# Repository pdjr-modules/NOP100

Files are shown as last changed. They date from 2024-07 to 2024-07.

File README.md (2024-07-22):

# NOP100

The **NOP100** project implements an
[NMEA 2000](https://en.wikipedia.org/wiki/NMEA_2000)
interface module with twin
[MikroBUS](https://www.mikroe.com/mikrobus)
sockets which allow specialisation of function by the addition of
[Click](https://www.mikroe.com/click) expansion cards.

[**NOP100** hardware](./hardware/README.md)
is based on the Teensy 4.0 micro-controller supported by a CAN
transceiver, parasitic power supply and a user configuration
interface.

[**NOP100** firmware](./firmware/README.md)
manages NMEA 2000 connectivity, user interaction and module
configuration and is easily extended by the addition of firmware
dedicated to operation of the installed MikroBus cards and the
integration of their function with NMEA 2000.

## Project organisation

```
NOP100/
  + firmware/            # NOP100 firmware...
    + modules/           # Folders for module specialisations
      + NOP100-SIM/        # Specialisation defining an NMEA switch input module
        + defines.h
        + definitions.h
        + includes.h
        + loop.h
        + setup.h
      + another module specialisation/
      + .../
    + NOP100.cpp         # NOP100 main application 
    + README.md
    + defines.h          # Symbolic link to a module specialisation
    + definitions.h      #   "       "
    + includes.h         #   "       "
    + loop.h             #   "       "
    + setup.h            #   "       "
  + hardware/            # NOP100 hardware...
    + gerber/            # Gerber files for PCB fabrication
    + kicad/             # Kicad design for the NOP100 motherboard
    + README.md
```

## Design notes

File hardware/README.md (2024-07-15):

# NOP100 hardware

This project thread provides a circuit design and PCB layout for an
NMEA 2000 interface module which uses
[MikroBus](https://www.mikroe.com/mikrobus)
[Click](https://mikroe.com/click) cards as its real-world interfaces.

The module is based on the
[Teensy 4.0](https://www.pjrc.com/teensy_40)
micro-controller supported by an
[MCP2551](https://www.microchip.com/en-us/product/mcp2551)
CAN transceiver, and single or twin
[Murata](https://www.murata.com/en-eu/)
power supplies.

<table border="0">
<tr>
<td width="50%">

</td>
<td>
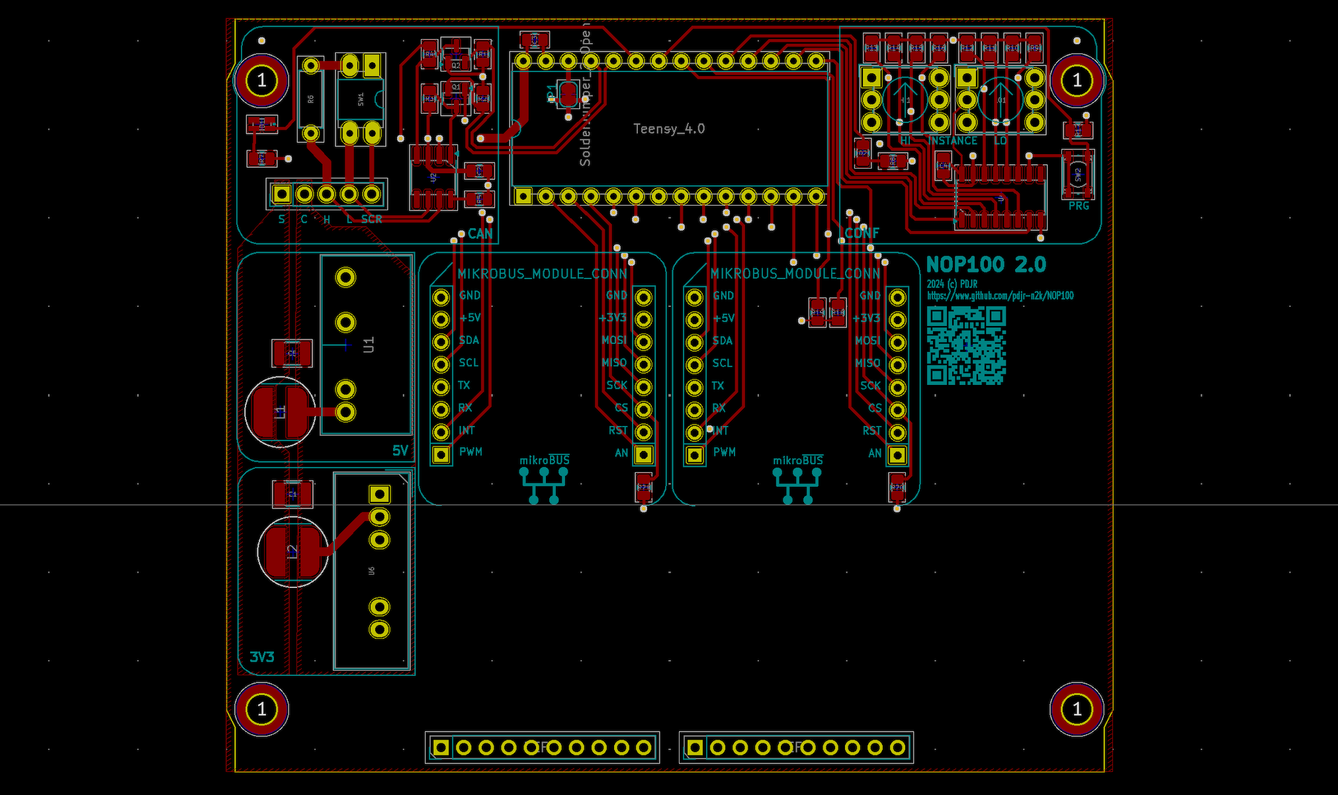
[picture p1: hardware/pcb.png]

</td>
</tr>
</table>

See [NOP100/firmware](../firmware/) for a C++ pattern and associated
libraries that can be used as a basis for implementing firmware which
exploits this hardware design.

## Design elements

### PCB and enclosure

The four-layer PCB is suitable for use in a
[Hammond 1591GSFLBK case](https://docs.rs-online.com/b790/A700000007521666.pdf)
and uses both surface-mount and through-hole components.

### Microcontroller

[Teensy 4.0](https://www.pjrc.com/store/teensy40.html).

### Power supplies

The module is a dual-voltage (5VDC/3.3VDC) design and is powered from
the host NMEA bus 12VDC supply.

A DC-DC converter outputs 5VDC 400mA to the microcontroller and CAN
transceiver.
In situations where the installed MikroBus modules have a current draw
of less that 250mA the Teensy's on-board 3.3VDC voltage regulator can
be used as the supply for all 3.3VDC consumers by making a solder
bridge connection at JP1.

If the Teensy's 250mA limit is insufficient for MikroBus consumers,
then a 3.3VDC 600mA DC-DC converter can be installed on the module PCB
(in which case the solder-bridge connection must not be made).

### CAN interface

An MCP-2551/IP CAN transceiver converts data on the NMEA bus
(CAN-H/CAN-L) to signals suitable for use by the microcontroller CAN
interface.
Input and output signals are level-shifted to 3.3VDC for compatability
with the Teensy 4.0.

A switch switch-selectable 120 Ohm bus termination resistor allows the
module to be used as either an NMEA drop or terminal node and a second
switch allows the NMEA bus shield to be connected to the module GND.

An activity indicator LED shows when the CAN interface is transmitting.

### Configuration interface

The configuration interface consists of two 4-bit rotary switches, a
momentary tactile switch and an LED.
The rotary switches are used to set the module's NMEA instance but can
also be used in concert with the tactile switch to save module
configuration parameters to EEPROM.

### MikroBus sockets

The **NOP100** hardware is specialised by inserting appropriate MikroBus
Click modules into the two MikroBus connector sockets.

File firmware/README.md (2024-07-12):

# NOP100/firmware

```NOP100.cpp``` implements a runnable, extensible, firmware for
[NOP100-based hardware](../hardware/README.md).

The files defines.h, definitions.h, includes.h, loop.h and setup.h
allow specialisation of NOP100 to a particular application by
extending and overriding some core functionality.

If the specialisation files are absent, the firmware creates an NMEA
2000 device with Class Code 10 (System Tools) and Function Code 130
(Diagnostic).
The created device is entirely passive.

Supplying functional content in the specialisation files allows the
construction of a useful NMEA 2000 application.
The recommended way of doing this is to create a folder under the
```modules/``` directory for a planned application and to populate this
with specialisation files that become the target of symbolic links in
the NOP100 folder.

By way of illustration, the ```modules/NOP100-SIM``` folders contains
code which specialises the NOP100 firmware so that it acts as an NMEA
2000 switch input module.
The extended firware supports one or two
[MikroE 5981]()
modules as the external switch input interface.

The modules/CLICK5981 folder, for example, 
Most useful applications will exploit interfaces implemented by
MikroBus modules which plug into the NOP100 motherboard and it is
[SIM108 - NMEA 2000 switch input module](https://www.github.com/preeve9534/SIM108/)
project is based on NOP100 and gives a working example of a real-world
application.

## Module configuration

NOP100 treats persistent configuration data as a simple byte array and
provides a user interface which allows the hardware DIL switch to be  
used sequentially to specify a storage address and the value to be
stored at that address.
This restricts the configuration data cache to a size of 256 bytes with
254 bytes available to the application.
The Teensy microcontroller has a about 1KB of EEPROM available and if
you want to access more than 256 bytes of this storage then you will
need to override NOP100's simple configuration model with a more
elaborate one of your own.
If you do this, make sure that your application configuration data
leaves address locations 0 and 1 for use by NOP100.

| Address | Saved value |
| ---:    | :---        |
| 0       | CAN source address. Not available for application use. |
| 1       | Module instance number. Not available for application use. |
| 2...    | Available for application use. |

Entry of configuration data into NOP100 requires a value to be set on
the PCB's DIL switch and then confirmed by press and release of the PRG
button.
A short press of PRG signifies the entry of a data value; a long press
of PRG signifies entry of an address and, in this latter case, the
expectation is that address entry will promptly be followed by the
entry of a data value which should be stored at the pre-set address.

If a value is entered without a preceeding address then the entered
value is stored at address 1 and will become the module's new instance
number.

Storage locations with an address greater than or equal to two are
intended for application configuration data and entry of this data
requires the entry of an address followed by entry of the value to be
stored at this address.

When an address is entered, the transmit LED will flash rapidly
indicating that the system is waiting for entry of a data value.
If a data value is not entered within one minute the data entry protocol
will self-cancel (the transmit LED will stop flashing).

In ```NOP100.cpp``` the configuration process is handled by the
```prgButtonHandler(bool _state_, int _value_)``` function which is
called each time the PRG button is operated.
*state* will be true if the PRG button has been released or false if
the PRG button has been pressed.
In either case, *value* will be set to the current value read from the
DIL switch.

You can override NOP100's built-in behaviour by overriding the button
handler in ```module-declarations.inc```.
For example, the following code disables configuration entirely:
```
#define PRG_BUTTON_HANDLER
void prgButtonHandler(bool state, int value) {
   return;
}
```

## HOW TO

1. Create parent folder for your new application.
   ```
   $> mkdir n2k-projects
   $> cd n2k-projects
   ```
2. Clone a copy of the Arduino firmware build project and this
   project into separate sub-folders.
   ```
   $> git clone https://github.com/preeve9534/firmware-factory
   $> git clone https://github.com/preeve9534/NOP100
   ```
3. Make a directory for your new project and populate it.
   ```
   $> mkdir myapp
   $> cd myapp
   $> cp ../NOP100/NOP100.cpp myapp.cpp
   $> cp ../NOP100/*.inc .
   $> cd ..
   ```
   You can now delete the NOP100 project.
   ```
   rm -rf NOP100
   ```
4. Set up the build environment so that it points to your new
   project.
   ```
   $> cd firmware-factory/sketch
   $> rm src
   $> ln -s ../../myapp src
   $> cd ../..
   ```
   At this juncture you should be able to open the firmware-factory 
   project in your preferred build environment (I use Code) and
   compile a firmware for your application which does nothing. Well,
   not very much.
5. Edit the ```.inc``` files downloaded at (3) to tailor and
   extend the module firmware to the requirements of your
   application.  DO NOT MODIFY myapp.cpp.

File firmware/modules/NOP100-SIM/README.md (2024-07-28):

# NOP100-SIM

This firmware extension for
[NOP100](https://www.github.com/pdjr-n2k/NOP100)
supports one or two
[MikroE-5981 Digi Isolator 2 Click]()
MikroBus expansion cards providing an NMEA interface to a maximum of
sixteen external switch input channels.

Switch input channels are consolidated into a single NMEA switch bank
whose status is reported by broadcast of a PGN 127501 Binary Switch
Status message once every two seconds or immediately when a state
change is detected on any input channel.

## Hardware requirement

* 1 x NOP100 motherboard;
* A maximum of two [MikroE-5981 Digi Isolator 2 Click]() expansion cards.

## Build

Building the firmware requires that both
[firmware-factory]()
and
[NOP100](https://www.github.com/pdjr-n2k/NOP100)
are installed locally in the locations pointed to by ```${FF}``` and
```${NOP100}```.

```
$> cd "${FF}/sketch"
$> ln -s "${NOP100}/firmware" src
$> pushd src ; ./link-module NOP100-SIM ; popd
$> pio run
```

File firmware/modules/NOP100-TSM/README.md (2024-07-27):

# NOP100-TSM

This sub-project provides a firmware extension for
[NOP100](https://www.github.com/pdjr-n2k/NOP100)
which implements an 8-channel NMEA 2000 temperature sensor module.

The module supports up to eight
[DS18B20](https://www.analog.com/media/en/technical-documentation/data-sheets/ds18b20.pdf)
digital thermometers.

A **NOP100-TSM** module broadcasts a
[PGN 130316 Temperature, Extended Range](https://www.nmea.org/Assets/nmea%202000%20pgn%20130316%20corrigenda%20nmd%20version%202.100%20feb%202015.pdf)
message once every five seconds.

## Hardware requirement

* 1 x NOP100 motherboard;
* 1 x [MikroE 1892 I2C 1-Wire Click](https://www.mikroe.com/i2c-1-wire-click) expansion card;
* Up to 8 x DS18B20 temperature sensors.

## Build

Building the firmware requires that both
[firmware-factory]()
and
[NOP100](https://www.github.com/pdjr-n2k/NOP100)
are installed locally in the locations pointed to by ```${FF}``` and
```${NOP100}```.

```
$> cd "${FF}/sketch"
$> ln -s "${NOP100}/firmware" src
$> pushd src ; ./link-module NOP100-TSM ; popd
$> pio run
```

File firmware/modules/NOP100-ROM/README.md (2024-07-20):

# NOP100-ROM - NMEA 2000 relay output module

NOP100-ROM is a 6-channel NMEA 2000 relay output module based on 
[NOP100](https://www.github.com/pdjr-n2k/NOP100)
hardware and firmware.

NOP100-ROM exploits the
[MikroE 5981 Relay 5 Click]()
module as its external switch interface.
One or two modules can be plugged into the NOP100's MikroBus sockets
giving a maximum of 6 output channels.

NOP100-ROM firmware can be linked into the NOP100 source code by
executing the following command in the ```NOP100/firmware``` folder.
```
$> ./link-module NOP100-ROM
```
Subsequently, compiling code in ```NOP100/firmware/src``` folder will
generate NOP100-ROM firmware.

## NMEA interface

**NOP100-ROM** broadcasts a PGN 127501 Binary Switch Status message
once every two seconds or immediately when a state change is detected
on a relay on any of the connected MikroE 5675 modules.

**NOP100-ROM** listens for PGN 127502 messages and updates relays on
connected MikroE 5675 modules to reflect the commanded states.

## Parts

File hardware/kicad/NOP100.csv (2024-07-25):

Source: | /Users/preeve/Documents/GitHub/NOP100/hardware/kicad/NOP100.kicad_sch
Date: | Thursday, July 25, 2024 at 04:07:12 PM
Tool: | Eeschema 7.0.11
Generator: | /Applications/KiCad/KiCad.app/Contents/SharedSupport/plugins/bom_csv_grouped_by_value.py
Component Count: | 45
Collated Components:
Item | Qty | Reference(s) | Value | LibPart | Footprint | Datasheet | DNP
1 | 1 | C1 | 330nF | Device:C_Small | Resistor_SMD:R_1210_3225Metric | ~
2 | 3 | C2, C3, C4 | 100nF | Device:C_Small | Resistor_SMD:R_0805_2012Metric | ~
3 | 1 | C5 | 22uF | Device:C_Small | Resistor_SMD:R_1210_3225Metric | ~
4 | 1 | CON1 | CLICK MODULE 0 | pdjr:MIKROBUS_MODULE_CONN | plop:MIKROBUS_HOST_CONN
5 | 1 | CON2 | CLICK MODULE 1 | pdjr:MIKROBUS_MODULE_CONN | plop:MIKROBUS_HOST_CONN
6 | 1 | D1 | LED | Device:LED | LED_SMD:LED_Kingbright_APHBM2012_2x1.25mm | ~
7 | 1 | D2 | LED | Device:LED | Resistor_SMD:R_0805_2012Metric | ~
8 | 2 | HI1, LO1 | SW_Coded | Switch:SW_Coded | pdjr:Nidec_Copal_SH-7010C | ~
9 | 1 | J1 | CAN | Connector:Screw_Terminal_01x05 | Connector_PinHeader_2.54mm:PinHeader_1x05_P2.54mm_Vertical | ~
10 | 1 | JP1 | SolderJumper_2_Open | Jumper:SolderJumper_2_Open | Jumper:SolderJumper-2_P1.3mm_Bridged_RoundedPad1.0x1.5mm | ~
11 | 1 | L1 | 15uH | Device:L_Small | Inductor_SMD:L_Bourns_SRN6045TA | ~
12 | 1 | L2 | 500uH | Device:L_Small | Inductor_SMD:L_Bourns_SRN6045TA | ~
13 | 2 | Q1, Q2 | BSS138 | Transistor_FET:BSS138 | Package_TO_SOT_SMD:SOT-23 | https://www.onsemi.com/pub/Collateral/BSS138-D.PDF
14 | 4 | R1, R2, R3, R4 | 10K 0.125W | Device:R | Resistor_SMD:R_0805_2012Metric | ~
15 | 12 | R5, R9, R10, R11, R12, R13, R14, R15, R16, R17, R18, R19 | 4K7 0.125W | Device:R | Resistor_SMD:R_0805_2012Metric | ~
16 | 1 | R6 | 120R 0.5W | Device:R | Resistor_SMD:R_1206_3216Metric | ~
17 | 2 | R7, R8 | 560R | Device:R | Resistor_SMD:R_0805_2012Metric | ~
18 | 2 | R20, R21 | 100K 0.125W | Device:R | Resistor_SMD:R_0805_2012Metric | ~
19 | 1 | SW1 | BUS | Switch:SW_DIP_x02 | Package_DIP:DIP-4_W7.62mm_LongPads | ~
20 | 1 | SW2 | SW_Push | Switch:SW_Push | Button_Switch_SMD:SW_SPST_PTS810 | ~
21 | 1 | U1 | MURATA_MEJ2* | pdjr:MURATA_MEJ2* | pdjr:Murata-MEJ2* | https://power.murata.com/data/power/ncl/kdc_ncs1.pdf
22 | 1 | U2 | MCP2551-I-P | Interface_CAN_LIN:MCP2551-I-P | Package_SO:SOIC-8_3.9x4.9mm_P1.27mm | http://ww1.microchip.com/downloads/en/devicedoc/21667d.pdf
23 | 1 | U3 | Teensy_4.0 | pdjr:Teensy_4.0 | Package_DIP:DIP-28_W15.24mm
24 | 1 | U4 | 74HC165 | pdjr:74HC165 | Package_SO:SOIC-16_3.9x9.9mm_P1.27mm | https://assets.nexperia.com/documents/data-sheet/74HC_HCT165.pdf
25 | 1 | U6 | NCS1S1203SC | Converter_DCDC:NCS1S1203SC | Converter_DCDC:Converter_DCDC_Murata_NCS1SxxxxSC_THT | https://power.murata.com/data/power/ncl/kdc_ncs1.pdf

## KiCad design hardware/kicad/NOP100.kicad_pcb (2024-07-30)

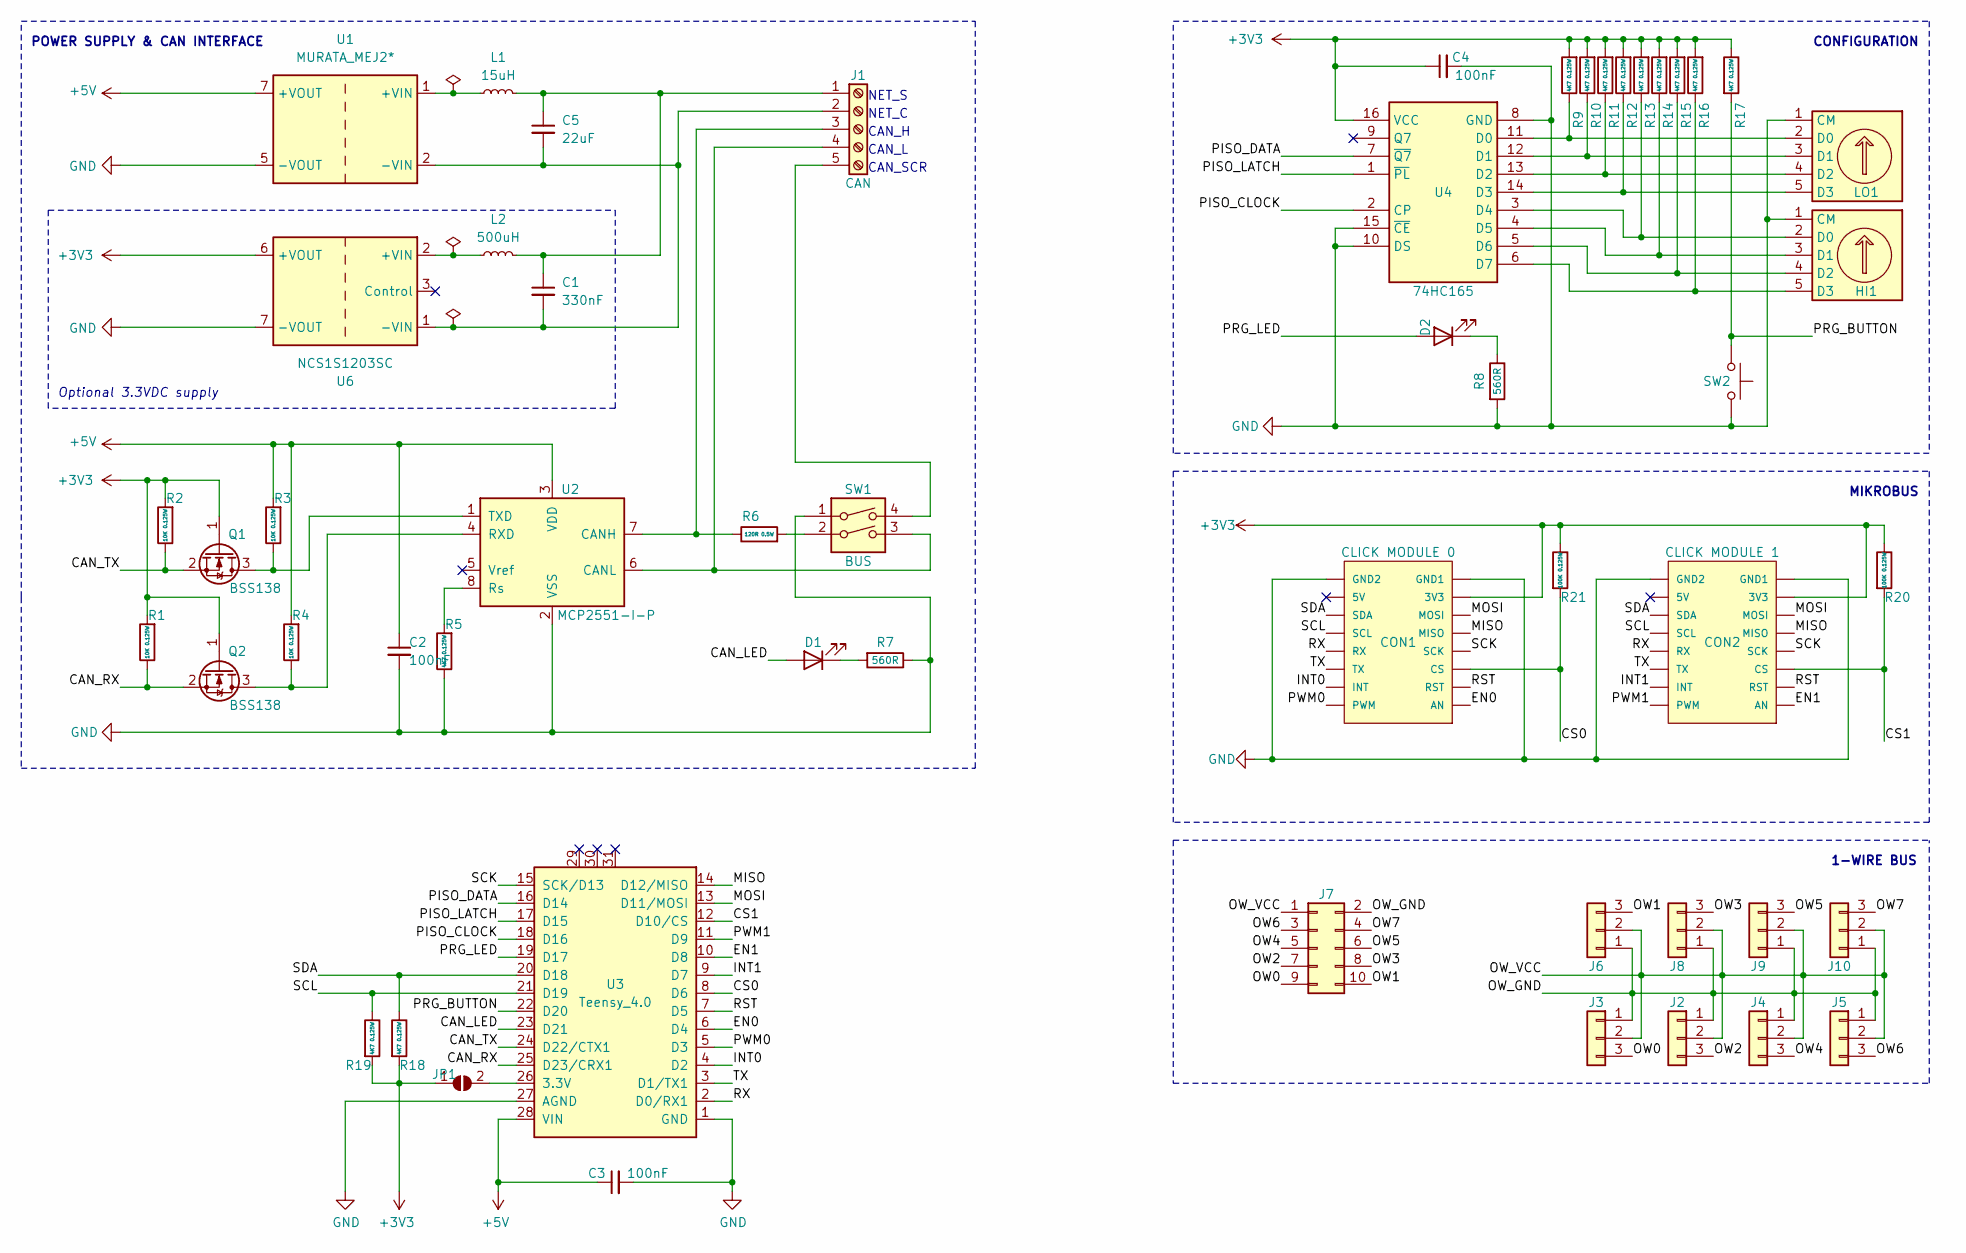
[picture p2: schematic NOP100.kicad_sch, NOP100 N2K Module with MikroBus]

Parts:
C1: 330nF; R_1210_3225Metric
C2, C3, C4: 100nF; R_0805_2012Metric
C5: 22uF; R_1210_3225Metric
CON1: CLICK MODULE 0; MIKROBUS_HOST_CONN
CON2: CLICK MODULE 1; MIKROBUS_HOST_CONN
D1: LED; LED_Kingbright_APHBM2012_2x1.25mm
D2: LED; R_0805_2012Metric
HI1: SW_Coded; Nidec_Copal_SH-7010C
J1: CAN; PinHeader_1x05_P2.54mm_Vertical
J2, J3, J4, J5, J6, J8, J9, J10: Conn_01x03; RS_8971054
J7: Conn_02x05_Odd_Even; PinSocket_2x05_P2.54mm_Vertical
JP1: SolderJumper_2_Open; SolderJumper-2_P1.3mm_Bridged_RoundedPad1.0x1.5mm
L1: 15uH; L_Bourns_SRN6045TA
L2: 500uH; L_Bourns_SRN6045TA
LO1: SW_Coded; Nidec_Copal_SH-7010C
Q1, Q2: BSS138; SOT-23
R1, R2, R3, R4: 10K 0.125W; R_0805_2012Metric
R5, R9, R10, R11, R12, R13, R14, R15, R16, R17, R18, R19: 4K7 0.125W; R_0805_2012Metric
R6: 120R 0.5W; R_1206_3216Metric
R7, R8: 560R; R_0805_2012Metric
R20, R21: 100K 0.125W; R_0805_2012Metric
SW1: BUS; DIP-4_W7.62mm_LongPads
SW2: SW_Push; SW_SPST_PTS810
U1: MURATA_MEJ2*; Murata-MEJ2*
U2: MCP2551-I-P; SOIC-8_3.9x4.9mm_P1.27mm
U3: Teensy_4.0; DIP-28_W15.24mm
U4: 74HC165; SOIC-16_3.9x9.9mm_P1.27mm
U6: NCS1S1203SC; Converter_DCDC_Murata_NCS1SxxxxSC_THT

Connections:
+3V3: C4.1, CON1.P7 (3V3), CON2.P7 (3V3), JP1.1 (A), Q1.1 (G), Q2.1 (G), R1.2, R2.2, R9.2, R10.2, R11.2, R12.2, R13.2, R14.2, R15.2, R16.2, R17.1, R18.2, R19.2, R20.1, R21.1, U4.16 (VCC), U6.6 (+VOUT)
+5V: C2.1, C3.1, R3.2, R4.2, U1.7 (+VOUT), U2.3 (VDD), U3.28 (VIN)
/CAN_LED: D1.2 (A), U3.23 (D21)
/CAN_RX: Q2.2 (S), R1.1, U3.25 (D23/CRX1)
/CAN_TX: Q1.2 (S), R2.1, U3.24 (D22/CTX1)
/CS0: CON1.P3 (CS), R21.2, U3.8 (D6)
/CS1: CON2.P3 (CS), R20.2, U3.12 (D10/CS)
/EN0: CON1.P1 (AN), U3.6 (D4)
/EN1: CON2.P1 (AN), U3.10 (D8)
/INT0: CON1.P15 (INT), U3.4 (D2)
/INT1: CON2.P15 (INT), U3.9 (D7)
/MISO: CON1.P5 (MISO), CON2.P5 (MISO), U3.14 (D12/MISO)
/MOSI: CON1.P6 (MOSI), CON2.P6 (MOSI), U3.13 (D11/MOSI)
/OW0: J3.3, J7.9
/OW1: J6.3, J7.10
/OW2: J2.3, J7.7
/OW3: J7.8, J8.3
/OW4: J4.3, J7.5
/OW5: J7.6, J9.3
/OW6: J5.3, J7.3
/OW7: J7.4, J10.3
/OW_GND: J2.1, J3.1, J4.1, J5.1, J6.1, J7.2, J8.1, J9.1, J10.1
/OW_VCC: J2.2, J3.2, J4.2, J5.2, J6.2, J7.1, J8.2, J9.2, J10.2
/PISO_CLOCK: U3.18 (D16), U4.2 (CP)
/PISO_DATA: U3.16 (D14), U4.7 (~Q7)
/PISO_LATCH: U3.17 (D15), U4.1 (~PL)
/PRG_BUTTON: R17.2, SW2.1, U3.22 (D20)
/PRG_LED: D2.2 (A), U3.19 (D17)
/PWM0: CON1.P16 (PWM), U3.5 (D3)
/PWM1: CON2.P16 (PWM), U3.11 (D9)
/RST: CON1.P2 (RST), CON2.P2 (RST), U3.7 (D5)
/RX: CON1.P13 (RX), CON2.P13 (RX), U3.2 (D0/RX1)
/SCK: CON1.P4 (SCK), CON2.P4 (SCK), U3.15 (SCK/D13)
/SCL: CON1.P12 (SCL), CON2.P12 (SCL), R19.1, U3.21 (D19)
/SDA: CON1.P11 (SDA), CON2.P11 (SDA), R18.1, U3.20 (D18)
/TX: CON1.P14 (TX), CON2.P14 (TX), U3.3 (D1/TX1)
GND: C2.2, C3.2, C4.2, CON1.P8 (GND1), CON1.P9 (GND2), CON2.P8 (GND1), CON2.P9 (GND2), HI1.1 (CM), LO1.1 (CM), R5.1, R7.1, R8.2, SW1.1, SW2.2, U1.5 (-VOUT), U2.2 (VSS), U3.1 (GND), U3.27 (AGND), U4.8 (GND), U4.10 (DS), U4.15 (~CE), U6.7 (-VOUT)
unnamed: D1.1 (K), R7.2
unnamed: D2.1 (K), R8.1
unnamed: HI1.2 (D0), R13.1, U4.3 (D4)
unnamed: HI1.3 (D1), R14.1, U4.4 (D5)
unnamed: HI1.4 (D2), R15.1, U4.5 (D6)
unnamed: HI1.5 (D3), R16.1, U4.6 (D7)
unnamed: C1.1, C5.1, J1.1, L1.2, L2.2
unnamed: C1.2, C5.2, J1.2, U1.2 (-VIN), U6.1 (-VIN)
unnamed: J1.3, R6.1, U2.7 (CANH)
unnamed: J1.4, SW1.3, U2.6 (CANL)
unnamed: J1.5, SW1.4
unnamed: JP1.2 (B), U3.26 (3.3V)
unnamed: LO1.2 (D0), R9.1, U4.11 (D0)
unnamed: LO1.3 (D1), R10.1, U4.12 (D1)
unnamed: LO1.4 (D2), R11.1, U4.13 (D2)
unnamed: LO1.5 (D3), R12.1, U4.14 (D3)
unnamed: Q1.3 (D), R3.1, U2.1 (TXD)
unnamed: Q2.3 (D), R4.1, U2.4 (RXD)
unnamed: R6.2, SW1.2
unnamed: L1.1, U1.1 (+VIN)
unnamed: R5.2, U2.8 (Rs)
unnamed: L2.1, U6.2 (+VIN)

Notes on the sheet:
CONFIGURATION
1-WIRE BUS
MIKROBUS
CAN_H
POWER SUPPLY & CAN INTERFACE
CAN_L
CAN_SCR
NET_C
NET_S
Optional 3.3VDC supply

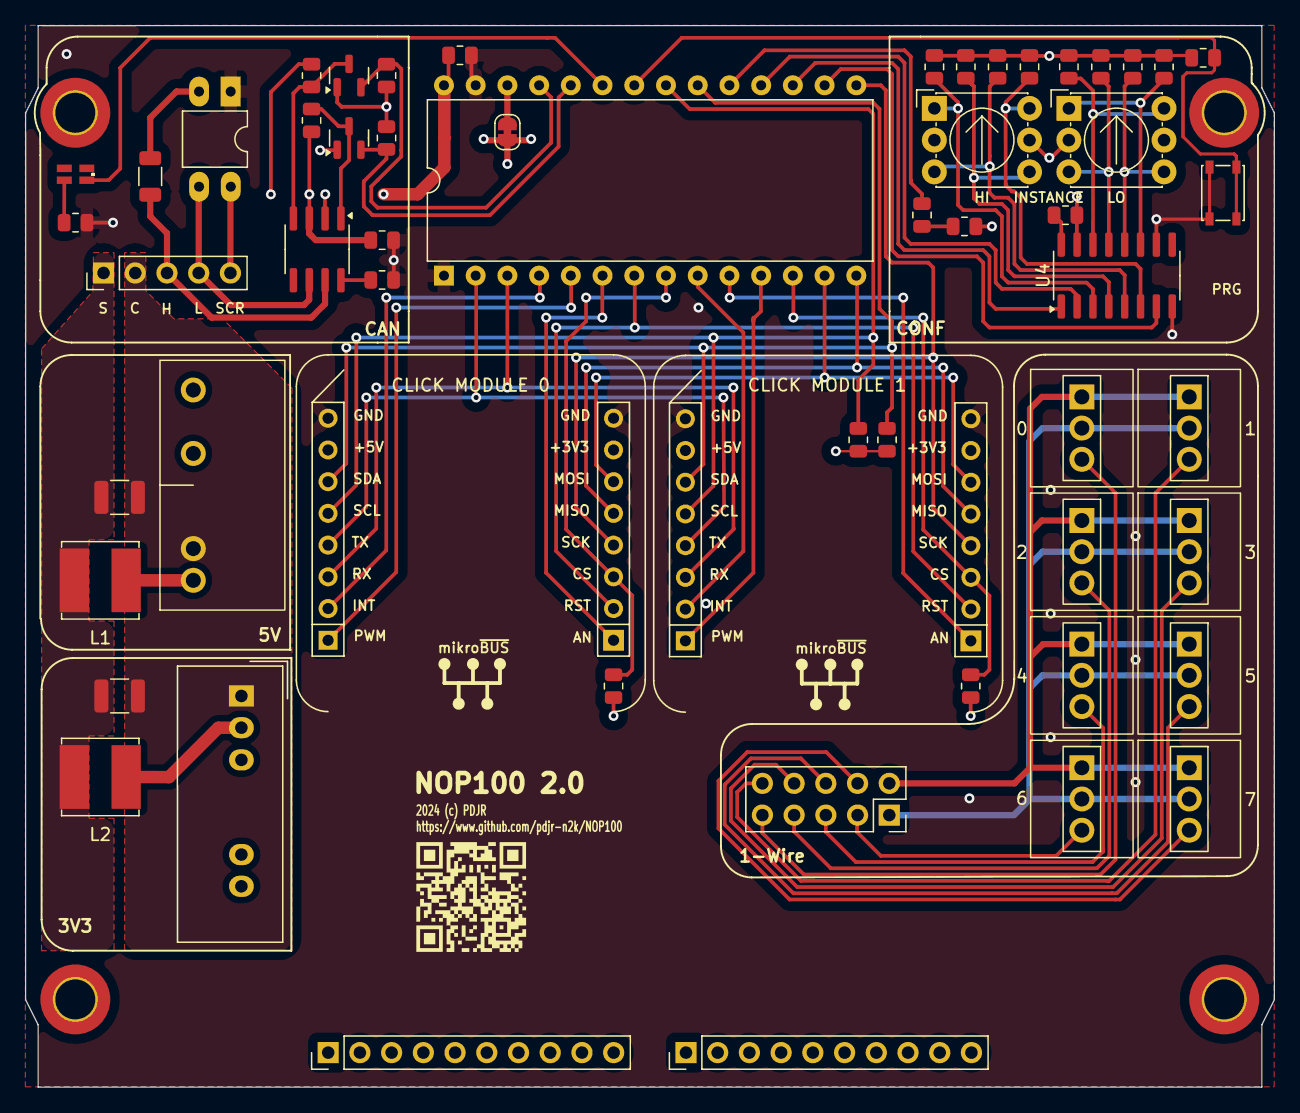
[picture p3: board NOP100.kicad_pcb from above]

Board: 4 copper layers, 100.0 x 85.0 mm, 54 parts (0 on the bottom side), 59 nets.

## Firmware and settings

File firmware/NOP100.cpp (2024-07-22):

/**
 * @file NOP100.cpp
 * @author Paul Reeve (preeve@pdjr.eu)
 * @brief Extensible firmware based on the NMEA2000 library.
 * @version 0.1
 * @date 2023-01-15
 * 
 * @copyright Copyright (c) 2023
 *
 * This firmware is targetted at hardware based on the
 * [NOP100](https://github.com/preeve9534/NOP100)
 * module design.
 * It implements a functional NMEA 2000 device that performs no
 * real-world task, but which can be easily extended or specialised
 * into a variant that can perform most things required of an NMEA 2000
 * module.
 * 
 * Support for NMEA 2000 networking is provided by Timo Lappalainen's
 * [NMEA2000](https://github.com/ttlappalainen/NMEA2000)
 * library.
 * 
 * Support for configuration management and operator interaction
 * is provided by a number of bespoke libraries that relieve derived
 * applications of much of the heavy lifting.
 */

#include <Arduino.h>
#include <EEPROM.h>
#include <NMEA2000.h>
#include <N2kTypes.h>
#include <N2kMessages.h>
#include <NMEA2000_Teensyx.h>
#include <NMEA2000_CAN.h>
#include <Button.h>
#include <IC74HC165.h>
#include <SPI.h>
#include <LedManager.h>
#include <ModuleOperatorInterface.h>
#include <ModuleConfiguration.h>
#include <FunctionMapper.h>
#include <arraymacros.h>

#include "includes.h"

/**********************************************************************
 * @brief Configure debug output to Teensy serial port.
 */
#define DEBUG_SERIAL
#define DEBUG_SERIAL_PORT_SPEED 9600
#define DEBUG_SERIAL_START_DELAY 4000

/**********************************************************************
 * @brief GPIO pin definitions for Teensy 4.0
 */
#define GPIO_D0 0
#define GPIO_D1 1
#define GPIO_D2 2
#define GPIO_D3 3
#define GPIO_D4 4
#define GPIO_D5 5
#define GPIO_D6 6
#define GPIO_D7 7
#define GPIO_D8 8
#define GPIO_D9 9
#define GPIO_D10 10
#define GPIO_D11 11
#define GPIO_D12 12
#define GPIO_D13 13
#define GPIO_D14 14
#define GPIO_D15 15
#define GPIO_D16 16
#define GPIO_D17 17
#define GPIO_D18 18
#define GPIO_D19 19
#define GPIO_D20 20
#define GPIO_D21 21
#define GPIO_D22 22
#define GPIO_D23 23

#define GPIO_SERIAL_RX GPIO_D0
#define GPIO_SERIAL_TX GPIO_D1
#define GPIO_MIKROBUS_MODULE0_INT GPIO_D2
#define GPIO_MIKROBUS_MODULE0_PWM GPIO_D3
#define GPIO_MIKROBUS_MODULE0_EN GPIO_D4
#define GPIO_MIKROBUS_RST GPIO_D5
#define GPIO_MIKROBUS_MODULE0_CS GPIO_D6
#define GPIO_MIKROBUS_MODULE1_INT GPIO_D7
#define GPIO_MIKROBUS_MODULE1_EN GPIO_D8
#define GPIO_MIKROBUS_MODULE1_PWM GPIO_D9
#define GPIO_MIKROBUS_MODULE1_CS GPIO_D10
#define GPIO_SPI_MOSI GPIO_D11
#define GPIO_SPI_MISO GPIO_D12
#define GPIO_SPI_SCK GPIO_D13
#define GPIO_PISO_DATA GPIO_D14
#define GPIO_PISO_LATCH GPIO_D15
#define GPIO_PISO_CLOCK GPIO_D16
#define GPIO_LED_PRG GPIO_D17
#define GPIO_I2C_SDA GPIO_D18
#define GPIO_I2C_SCL GPIO_D19
#define GPIO_BUTTON_PRG GPIO_D20
#define GPIO_LED_CAN GPIO_D21
#define GPIO_CAN_TX GPIO_D22
#define GPIO_CAN_RX GPIO_D23

/**********************************************************************
 * @brief NMEA2000 device information.
 * 
 * Most specialisations of NOP100 will want to override DEVICE_CLASS,
 * DEVICE_FUNCTION and perhaps DEVICE_UNIQUE_NUMBER.
 * 
 * DEVICE_CLASS and DEVICE_FUNCTION are explained in the document
 * "NMEA 2000 Appendix B.6 Class & Function Codes".
 * 
 * DEVICE_INDUSTRY_GROUP we can be confident about (4 says maritime).
 * 
 * DEVICE_MANUFACTURER_CODE is only allocated to subscribed NMEA
 * members so we grub around and use 2046 which is currently not
 * allocated.  
 * 
 * DEVICE_UNIQUE_NUMBER is a bit of mystery.
 */
#define DEVICE_CLASS 10                 // System Tools
#define DEVICE_FUNCTION 130             // Diagnostic
#define DEVICE_INDUSTRY_GROUP 4         // Maritime
#define DEVICE_MANUFACTURER_CODE 2046   // Currently not allocated.
#define DEVICE_UNIQUE_NUMBER 849        // Bump me?

/**********************************************************************
 * @brief NMEA2000 product information.
 * 
 * Specialisations of NOP100 will want to override most of these.
 * 
 * PRODUCT_CERTIFICATION_LEVEL is granted by NMEA when a product is
 * officially certified. We won't be.
 * 
 * PRODUCT_CODE is our own unique numerical identifier for this device.
 * 
 * PRODUCT_FIRMWARE_VERSION should probably be generated automatically
 * from semewhere.
 * 
 * PRODUCT_LEN specifies the Load Equivalence Network number for the
 * product which encodes the normal power loading placed on the host
 * NMEA bus. One LEN = 50mA and values are rounded up.
 * 
 * PRODUCT_N2K_VERSION is the version of the N2K specification witht
 * which the firmware complies. 
 */
#define PRODUCT_CERTIFICATION_LEVEL 0   // Not certified
#define PRODUCT_CODE 002                // Our own product code
#define PRODUCT_FIRMWARE_VERSION "1.1.0 (Jun 2022)"
#define PRODUCT_LEN 1                   // This device's LEN
#define PRODUCT_N2K_VERSION 2100        // N2K specification version 2.1
#define PRODUCT_SERIAL_CODE "002-849"   // PRODUCT_CODE + DEVICE_UNIQUE_NUMBER
#define PRODUCT_TYPE "PDJRSIM"           // The product name?
#define PRODUCT_VERSION "1.0 (Mar 2022)"

/**********************************************************************
 * @brief NMEA2000 transmit and receive PGNs.
 * 
 * NMEA_TRANSMITTED_PGNS is a zero terminated array initialiser that
 * lists all the PGNs we transmit.
 * 
 * NMEA_RECEIVED_PGNS is a an array initialiser consisting of pairs
 * which associate the PGN of a message we will accept to a callback
 * which will accept a received message. For example,
 * { 127501L, handlerForPgn127501 }. The list must terminate with the
 * special flag value { 0L, 0 }.
 */
#define NMEA_TRANSMITTED_PGNS { 0L }
#define NMEA_RECEIVED_PGNS  { { 0L, 0 } }

/**********************************************************************
 * @brief ModuleConfiguration library stuff.
 */
#define MODULE_CONFIGURATION_SIZE 1
#define MODULE_CONFIGURATION_EEPROM_STORAGE_ADDRESS 0

#define MODULE_CONFIGURATION_CAN_SOURCE_INDEX 0
#define MODULE_CONFIGURATION_CAN_SOURCE_DEFAULT 22

#define MODULE_CONFIGURATION_DEFAULT { \
  MODULE_CONFIGURATION_CAN_SOURCE_DEFAULT \
}

/**********************************************************************
 * @brief FunctionMapper library stuff.
 * 
 * This provides just one function that wipes configuration data from
 * EEPROM. A specialisation of NOP100 that needs to add functions to
 * the function mapper will need to increase FUNCTION_MAPPER_SIZE
 * appropriately.
 */
#define FUNCTION_MAP_ARRAY { { 255, [](unsigned char i, unsigned char v) -> bool { ModuleConfiguration.erase(); return(true); } }, { 0, 0 } };
#define FUNCTION_MAPPER_SIZE 0

/**********************************************************************
 * @brief ModuleOperatorInterface library stuff.
 */
#define MODULE_OPERATOR_INTERFACE_LONG_BUTTON_PRESS_INTERVAL 1000UL
#define MODULE_OPERATOR_INTERFACE_DIALOG_INACTIVITY_TIMEOUT 30000UL

/**********************************************************************
 * @brief LedManager library stuff.
 *
 * NOP100 supports two LEDs: one used to indicate CAN bus activity and
 * one to provide feedback in the configuration user-interface.
 */
#define CAN_LED_UPDATE_INTERVAL 100UL
#define PRG_LED_UPDATE_INTERVAL 100UL

#include "defines.h"

/**
 * @brief Declarations of local functions.
 */
void messageHandler(const tN2kMsg&);
void onN2kOpen();
bool configurationValidator(unsigned int index, unsigned char value);

/**
 * @brief Create and initialise an array of transmitted PGNs.
 * 
 * Array initialiser is specified in defined.h. Required by NMEA2000
 * library. 
 */
const unsigned long TransmitMessages[] = NMEA_TRANSMITTED_PGNS;

/**
 * @brief Create and initialise a vector of received PGNs and their
 *        handlers.
 * 
 * Array initialiser is specified in defined.h. Required by NMEA2000
 * library. 
 */
typedef struct { unsigned long PGN; void (*Handler)(const tN2kMsg &N2kMsg); } tNMEA2000Handler;
tNMEA2000Handler NMEA2000Handlers[] = NMEA_RECEIVED_PGNS;

/**
 * @brief Create a ModuleConfiguration object for managing all module
 *        configuration data.
 * 
 * ModuleConfiguration implements the ModuleOperatorInterfaceHandler interface
 * and can be managed by the user-interaction manager.
*/
unsigned char defaultConfiguration[] = MODULE_CONFIGURATION_DEFAULT;
ModuleConfiguration ModuleConfiguration(defaultConfiguration, MODULE_CONFIGURATION_SIZE, MODULE_CONFIGURATION_EEPROM_STORAGE_ADDRESS, configurationValidator);

/**
 * @brief Create a FunctionHandler object for managing all extended
 *        configuration functions.
 * 
 * FunctionHandler implements the ModuleOperatorInterfaceHandler interface
 * and can be managed by the user-interaction manager. We'all add
 * functions later in setup().
 */
FunctionMapper::FunctionMap functionMapArray[] = FUNCTION_MAP_ARRAY;
FunctionMapper FunctionMapper(functionMapArray, FUNCTION_MAPPER_SIZE);

/**
 * @brief Create a ModuleOperatorInterface supporting ModuleConfiguration and
 *        FunctionHandler objects.
 */
ModuleOperatorInterfaceClient *modeHandlers[] = { &ModuleConfiguration, &FunctionMapper, 0 };
ModuleOperatorInterface ModuleOperatorInterface(modeHandlers);

/**
 * @brief Button object for debouncing the module's PRG button.
 */
Button PRGButton(GPIO_BUTTON_PRG);

/**
 * @brief Interface to the IC74HC165 PISO IC that connects the eight 
 *        DIL switch parallel inputs.
 */
IC74HC165 CodeSwitchPISO (GPIO_PISO_CLOCK, GPIO_PISO_DATA, GPIO_PISO_LATCH);

/**
 * @brief tLedManager objects for operating the CAN and PRG LEDs.
 * 
 * Both LEDs are connected directly to a GPIO pin, so the lambda
 * callback just uses a digital write operation to drive the output.
 */
LedManager CanLed([](unsigned int status){ digitalWrite(GPIO_LED_CAN, (status & 0x01)); }, CAN_LED_UPDATE_INTERVAL);
LedManager PrgLed([](unsigned int status){ digitalWrite(GPIO_LED_PRG, (status & 0x01)); }, PRG_LED_UPDATE_INTERVAL);

#include "definitions.h"

/**********************************************************************
 * MAIN PROGRAM - setup()
 */
void setup() {
  #ifdef DEBUG_SERIAL
  Serial.begin(DEBUG_SERIAL_PORT_SPEED);
  delay(DEBUG_SERIAL_START_DELAY);
  #endif

  // Set the mode of GPIO pins which are not configured by interface
  // libraries.
  pinMode(GPIO_MIKROBUS_MODULE0_CS, OUTPUT);
  pinMode(GPIO_MIKROBUS_MODULE1_CS, OUTPUT);
  pinMode(GPIO_LED_CAN, OUTPUT);
  pinMode(GPIO_LED_PRG, OUTPUT);

  SPI.begin();

  PRGButton.begin();

  CodeSwitchPISO.begin();
  
  // Run a startup sequence in the LED display: all LEDs on to confirm
  // function.
  CanLed.setStatus(0xff); PrgLed.setStatus(0xff);
  delay(100);
  CanLed.setStatus(0x00); PrgLed.setStatus(0x00);

  #include "setup.h"

  // Initialise and start N2K services.
  NMEA2000.SetProductInformation(PRODUCT_SERIAL_CODE, PRODUCT_CODE, PRODUCT_TYPE, PRODUCT_FIRMWARE_VERSION, PRODUCT_VERSION);
  NMEA2000.SetDeviceInformation(DEVICE_UNIQUE_NUMBER, DEVICE_FUNCTION, DEVICE_CLASS, DEVICE_MANUFACTURER_CODE);
  NMEA2000.SetMode(tNMEA2000::N2km_ListenAndNode, ModuleConfiguration.getByte(MODULE_CONFIGURATION_CAN_SOURCE_INDEX)); // Configure for sending and receiving.
  NMEA2000.EnableForward(false); // Disable all msg forwarding to USB (=Serial)
  NMEA2000.ExtendTransmitMessages(TransmitMessages); // Tell library which PGNs we transmit
  NMEA2000.SetMsgHandler(messageHandler);
  NMEA2000.SetOnOpen(onN2kOpen);
  NMEA2000.Open();

  #ifdef DEBUG_SERIAL
  Serial.println();
  Serial.println("Starting:");
  Serial.print("  N2K Source address is "); Serial.println(NMEA2000.GetN2kSource());
  #endif
}

/**********************************************************************
 * MAIN PROGRAM - loop()
 * 
 * With the exception of NMEA2000.parseMessages() all of the functions
 * called from loop() implement interval timers which ensure that they
 * will mostly return immediately, only performing their substantive
 * tasks at intervals defined by program constants.
 */ 
void loop() {
  
  // Before we transmit anything, let's do the NMEA housekeeping and
  // process any received messages. This call may result in acquisition
  // of a new CAN source address, so we check if there has been any
  // change and if so save the new address to EEPROM for future re-use.
  NMEA2000.ParseMessages();
  if (NMEA2000.ReadResetAddressChanged()) {
    ModuleConfiguration.setByte(MODULE_CONFIGURATION_CAN_SOURCE_INDEX, NMEA2000.GetN2kSource());
  }

  #include "loop.h"

  // If the PRG button has been operated, then call the button handler.
  if (PRGButton.toggled()) {
    switch (ModuleOperatorInterface.handleButtonEvent(PRGButton.read(), (unsigned char) (CodeSwitchPISO.read() & 0xff))) {
      case ModuleOperatorInterface::MODE_CHANGE:
        PrgLed.setLedState(0, LedManager::ONCE);
        break;
      case ModuleOperatorInterface::ADDRESS_ACCEPTED:
        PrgLed.setLedState(0, LedManager::ONCE);
        break;
      case ModuleOperatorInterface::ADDRESS_REJECTED:
        PrgLed.setLedState(0, LedManager::THRICE);
        break;
      case ModuleOperatorInterface::VALUE_ACCEPTED:
        PrgLed.setLedState(0, LedManager::ONCE);
        break;
      case ModuleOperatorInterface::VALUE_REJECTED:
        PrgLed.setLedState(0, LedManager::THRICE);
        break;
      default:
        break;
    }
  }

  // Update LED outputs.
  CanLed.update(); PrgLed.update();
  
  // Make sure that we always eventually revert to normal operation.
  ModuleOperatorInterface.revertModeMaybe();
}

void messageHandler(const tN2kMsg &N2kMsg) {
  int iHandler;
  for (iHandler=0; NMEA2000Handlers[iHandler].PGN!=0 && !(N2kMsg.PGN==NMEA2000Handlers[iHandler].PGN); iHandler++);
  if (NMEA2000Handlers[iHandler].PGN != 0) {
    NMEA2000Handlers[iHandler].Handler(N2kMsg); 
  }
}

#ifndef CONFIGURATION_VALIDATOR
/**
 * @brief ModuleConfiguration validation callback.
 * 
 * ModuleConfiguration uses this callback to validate update values
 * before they are written into the configuration.
 * 
 * @attention Specialisations will probably need to override this
 * function and therefore must define CONFIGURATION_VALIDATOR.
 * 
 * @param index - the configuration address where value will be stored
 * if validation is successful.
 * @param value - the proposed configuration value.
 * @return true - the proposed value is acceptable.
 * @return false - the proposed value is not acceptable.
 */
bool configurationValidator(unsigned int index, unsigned char value) {
  switch (index) {
    case MODULE_CONFIGURATION_CAN_SOURCE_INDEX:
      return(true);
    default:
      return(false);
  }
}
#endif

#ifndef ON_N2K_OPEN
/**
 * @brief Function called by the NMEA2000 library once the CAN bus is
 * active.
 * 
 * @attention Specialisations will probably need to override this
 * function and therefore must define ON_N2K_OPEN.
 */
void onN2kOpen() {
}
#endif

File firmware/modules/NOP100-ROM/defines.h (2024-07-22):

/**
 * @file defines.h
 * @author Paul Reeve (preeve@pdjr.eu)
 * @brief Defines for a relay output module based on Click 5675 modules.
 * @version 0.1
 * @date 2024-07-16
 * @copyright Copyright (c) 2024
 */

/**********************************************************************
 * @brief Specify the MikroBus sockets occupied by Click 5675 modules.
 * 
 * Options are MIKROBUS_SOCKET_LEFT, MIKROBUS_SOCKET_RIGHT or
 * MIKROBUS_SOCKET_LEFT_AND_RIGHT.
 */
#define MIKROBUS_SOCKET_LEFT_AND_RIGHT  // Both sockets

/**********************************************************************
 * @brief NMEA2000 device information overrides.
 */
#define DEVICE_CLASS 30                 // Electrical Distribution
#define DEVICE_FUNCTION 140             // Load controller
#define DEVICE_UNIQUE_NUMBER 108        // Bump me?

/**********************************************************************
 * @brief NMEA2000 product information overrides.
 */
#define PRODUCT_CODE 002
#define PRODUCT_FIRMWARE_VERSION "240716"
#define PRODUCT_LEN 1
#define PRODUCT_SERIAL_CODE "002-108"   // PRODUCT_CODE + DEVICE_UNIQUE_NUMBER
#define PRODUCT_TYPE "NOP100-ROM"           // The product name?
#define PRODUCT_VERSION "240716 (Jul 2024)"

/**********************************************************************
 * @brief NMEA2000 transmit and receive PGN overrides.
 */
#define NMEA_TRANSMITTED_PGNS { 127501L, 0 }
void handlePGN127502(const tN2kMsg &n2kMsg);
#define NMEA_RECEIVED_PGNS  { { 127502L, handlePGN127502 }, { 0L, 0 } }

/**********************************************************************
 * @brief ModuleConfiguration library stuff.
 */
#define MODULE_CONFIGURATION_SIZE 3                               // Total configuration size in bytes

#define MODULE_CONFIGURATION_PGN127501_TRANSMIT_PERIOD_INDEX 1    // Index of PGN 127501 transmit period in seconds
#define MODULE_CONFIGURATION_PGN127501_TRANSMIT_OFFSET_INDEX 2    // Index of PGN 127501 transmit offset in 10s of milli-seconds

#define MODULE_CONFIGURATION_TRANSMIT_PERIOD_DEFAULT 0x02         // Every two seconds
#define MODULE_CONFIGURATION_TRANSMIT_OFFSET_DEFAULT 0x00         // Zero times 10 milliseconds

#define MODULE_CONFIGURATION_DEFAULT { \
  MODULE_CONFIGURATION_CAN_SOURCE_DEFAULT, \
  MODULE_CONFIGURATION_TRANSMIT_PERIOD_DEFAULT, \
  MODULE_CONFIGURATION_TRANSMIT_OFFSET_DEFAULT \
}

/**********************************************************************
 * @brief NOP100 function overrides.
 */
#define CONFIGURATION_VALIDATOR
#define ON_N2K_OPEN

/**********************************************************************
 * @brief Configuration of attached Click 5675 modules.
 */
#define MIKROE5675_MODULE_0 { 0x70, GPIO_MIKROBUS_RST }
#define MIKROE5675_MODULE_1 { 0x71, GPIO_MIKROBUS_RST }

#ifdef MIKROBUS_SOCKET_LEFT
#define MIKROBUS_CONFIGURATION { MIKROE5675_MODULE_0, { 0,0 } }
#endif

#ifdef MIKROBUS_SOCKET_RIGHT
#define MIKROBUS_CONFIGURATION { MIKROE5675_MODULE_1, { 0,0 } }
#endif

#ifdef MIKROBUS_SOCKET_LEFT_AND_RIGHT
#define MIKROBUS_CONFIGURATION { MIKROE5675_MODULE_0, MIKROE5675_MODULE_1, { 0,0 } }
#endif

/**********************************************************************
 * @brief number of milliseconds between checks on switch input channel
 * states.
 */
#define SWITCHBANK_UPDATE_INTERVAL 100

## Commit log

2022-12-21 Add code
    [NOP100.kicad_pcb, NOP100.sch]
2022-12-21 Add testpomts
    [NOP100.kicad_pcb, NOP100.sch]
2022-12-22 Move grid
    [NOP100.kicad_pcb, NOP100.sch]
2022-12-22 Silk edit.
    [NOP100.kicad_pcb]
2023-01-04 Revise operation of transmit LED
2024-07-13 Convert micro vias to through vias.
    [NOP100.kicad_pcb]
2024-07-13 Revise mikrobus symbol
    [NOP100.kicad_sch]
2024-07-14 Add 3.3VDC alternatives.
    [NOP100.kicad_pcb, NOP100.kicad_sch]
2024-07-15 Library tweak
    [NOP100.kicad_pcb]
2024-07-15 Create Gerbers
    [NOP100.kicad_pcb, NOP100.kicad_sch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]
2024-07-20 Lots of tweaks
    [NOP100.csv, NOP100.kicad_pcb, NOP100.kicad_sch]
2024-07-22 Update GPIO assignments.
    [NOP100.kicad_pcb, NOP100.kicad_sch]
2024-07-23 Switch build.
    [NOP100.kicad_sch]
2024-07-27 New build
    [NOP100.kicad_pcb]
2024-07-27 Add 1-wire support
    [NOP100.kicad_pcb]
2024-07-30 Adjust fill zones.
    [NOP100.kicad_pcb]
